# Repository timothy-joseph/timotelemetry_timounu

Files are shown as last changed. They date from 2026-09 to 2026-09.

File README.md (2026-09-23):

Data aquisition and transmission system
---

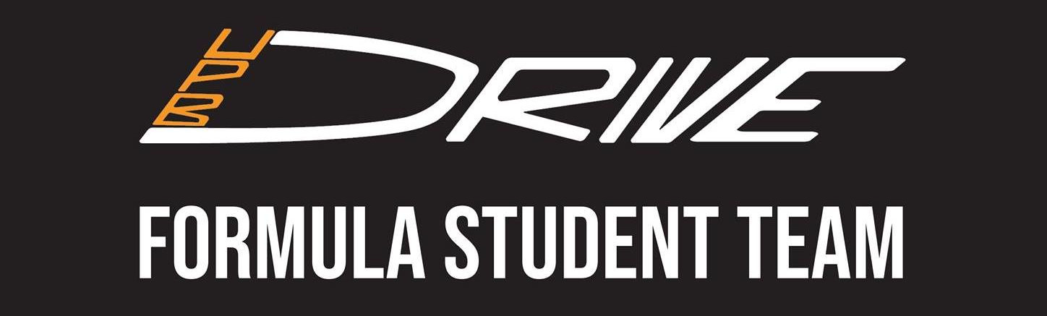
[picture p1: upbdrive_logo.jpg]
UPB Drive Logo UPB Drive logo


Formula Student Telemetry system I've developed in my first year of University
at UPB Drive

Kicad files are located in `Hardware/` and all software in `Software/` - th
firmware is located at `Software/dat\_software`, the GUI for the telemetry is
located at `Software/flask_mqtt_server`, and a helper program to load the
microsd logs in the interface is located at `Software/dat_microsd_log_to_json`

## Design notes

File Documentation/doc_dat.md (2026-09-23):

# Data acquisition and transmission

Purpose
---

The DAT system needs to collect data from the other modules and store it on a
microsd card, but also transmit it to the pits via 2 methods: MQTT and LoRa.\
The module also needs to have a RTC clock which will be set to either the time
retrieved via NTP or GPS at startup.\
The contents of the flash chip can be read by putting the module into a debug
mode and reading them through the onboard usb port.

Components used
---

### ESP32-S3-WROOM-1-N16R8

(TODO)

### Simcom7600e-h module from waveshare

This is the component that will handle data transmission via MQTT, but will
also get the current time and location of the vehicle.

The module has a UART interface using a 3 wire (TXD, RXD, GND) interface, but i
chose to also connect CTS and RTS for hardware control flow, DTR which puts the
module's uart interface in sleep mode, and RI which will cause a interrupt (high
to low) when receiving a phone call or sms. ([[1]] on page 7 to 11)\
Voltage in is between 5v and 26v, so I connected it to the 12v battery on the
car.\
The module also has a reset pin, which i connected to the esp32.
(Ground is connected to ground).\
All other pins can be left floating (as per the reference design or what i
deducted from the module schematic).

The module itself has a sim card slot and antenna inputs which will need to
be connected to a external antenna.

### LoRa-E5

This module provides LoRa wireless communication. It interfaces with the
microcontroller via a 3 wire (TXD, RXD, GND) UART interface, it also has a reset
pin, and a pin to enter boot upgrade mode. Besides these and power, all other
pins can be left floating as per the reference design. [[2]]

![Reference design](lora_reference_design.png "Reference design of the LoRa-E5
module")

### SN65HVD230DR

This is a CAN transciever with a speed for up to 1Mbps.

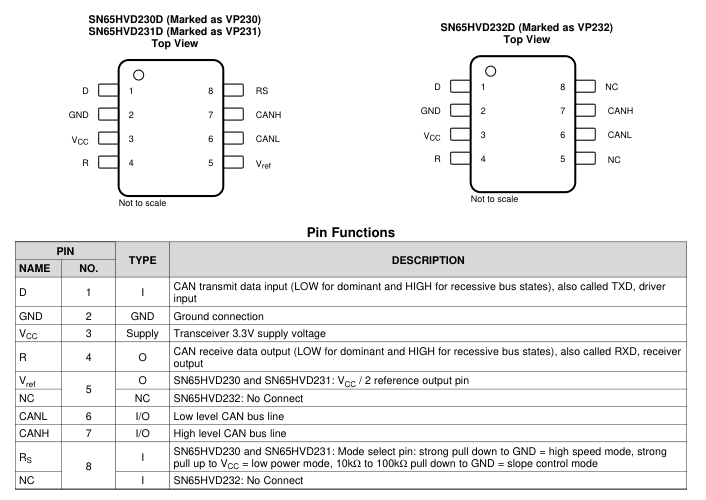
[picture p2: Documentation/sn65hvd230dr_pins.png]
SN65HVD230DR pins Pins of the SN65HVD230DR


### Miscrosd

The microsd is used to store logged data locally on multiple binary files.
The pins are connected according to the following reference design, but with
different IO pins on the esp32 side.

![Microsd reference](sch_micro_sd_slot.png "Reference design for the microsd
slot")

### MAX31331TETB+

The MAX31331TETB+ is a RTC chip with a backup supply pin, to which it will
switch automatically when the main supply drops below a programmed voltage.
The chip also features a trickle charger for the backup battery.
It is accessed through a I2C interface.

The VCC and GND pins are connected to the power supply.\
The SDA and SCL pins are connected to the I2C bus of the microcontroller.\
The X1 and X2 pins are connected to a external crystal.\
DIN is a input to the RTC and INTA is a interrupt generated by the RTC on:
Alarm2, timer, PFAIL, and DIN (configurable)\
INTB should be connected ground if unused.

![MAX31331TETB+ footprint](max31331tetb_footprint.png "The pins descriptions of
the MAX31331TETB+")
![MAX31331TETB+ pins](max31331tetb_pins.png "The pins descriptions of the
MAX31331TETB+")

### Power delivery

(TODO)

[1]: <https://www.microchip.ua/simcom/LTE/SIM7500_SIM7600/Application%20Notes/SIM7100_SIM7500_SIM7600%20Series_UART_Application%20Note_V3.00.pdf>
[2]: <https://files.seeedstudio.com/products/317990687/res/LoRa-E5%20module%20datasheet_V1.1.pdf> "LoRa-E5 datasheet"

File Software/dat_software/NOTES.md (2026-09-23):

### Dynamic Memory allocation

The rule "Dynamic allocation of memory is forbidden" has not been followed as
of writing this note, but the rule "Do not use dynamic memory allocation after
initialization" has been followed, except in one place.

Explanation:

- Besides the `can_receive_thread`, all other threads are created using the
  standard ESP's FreeRTOS `xTaskCreatePinnedToCore` which uses dynamic memory
  allocation (however, the stack's size does not change during operation)
  instead of `xTaskCreateStaticPinnedToCore`
- The esp idf's "release/v5.1" i2c driver uses dynamic memory allocation to
  create the command links

### MQTT packet

A mqtt packet is formed like this:

- 4 bytes representing the timestamp since logging began (us)
- 2 bytes representing the can id (made-up can id if it's not actually a can
  message)
- 1 byte representing data size
- a maximum of 8 data bytes

with 500-700 can messages per second => 60000 to 84000 bits per second of
packet data only. I might need to make the sim module's uart run at a higher
baud rate (higher than 400000)

The packet is in big-endian format.

### Driver configuration

When i set out to create the drivers for all of the peripherals of the DAT
system, i wanted them to be configurable in a similar way to how the drivers of
the esp-idf are configured, however due to time constraints, i have chosen to
make them configurable in another way: similar to how suckless software is
configured. All (configurable) components/drivers have a `component_config.h`
file which contains macros and/or variables to configure the driver's used
pins, stack sizes, thread priorities, queue sizes etc. These macros/variables
are explained briefly in comments above them and/or have suggestive names

### Sim driver

The sim driver has 3 components:

1. One to send commands
2. One to receive responses, interpret them and call callback functions (that
are defined within the same source file [this is another part that was rushed;
initially i wanted a system that binds responses to external callback
functions]);
3. One that enqueues the "AT+CGPSINFO" command every ??? (configurable) ms in
order to send it to the mqtt server

### RTC (MAX31331) chip's SDA and SCL pins

I accidentally swapped the SDA and SCL pins within the schematic when designing
it. That's why the pins are the swapped in software.

### Component initialization dependencies

rtc driver doesn't depend on anything
lora driver doesn't depend on anything
sim driver depends on rtc driver
microsd driver depends on rtc driver, sim driver
logging driver depends on sim driver, microsd driver, rtc driver, lora driver
can driver depends on logging

additionally the rtc driver has only one function that depends on the can
driver and so does the sim driver.

So the component initialization order is as follows:
1. can driver
2. rtc driver
3. sim driver
3.5 wait for the sim module to send the RDY flag (with a timeout)
4. lora driver
5. microsd driver and file
6. logging driver
7. can thread

`rtc_start_periodic_can_msg()` needs to be started from inside the receive
thread of the can driver

It might be a good idea to wait for the sim module to be ready before
initializing the microsd component. So the places that will wait for the sim
module are:

1. The `sim_commands_queue_thread` thread
2. `dat_setup()`

These places will have a timeout

\*: the module already `sim_commands_queue_thread()` already waits for the RDY
flag to be sent so it doesn't send any commands to the module before it's
initialized, but i think it's a good idea to wait in the `dat_setup()` function
also so the whole system is somewhat synced

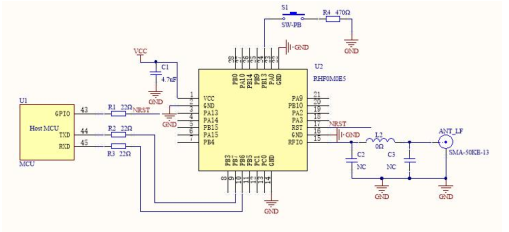
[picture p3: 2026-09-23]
Documentation/lora_reference_design.png

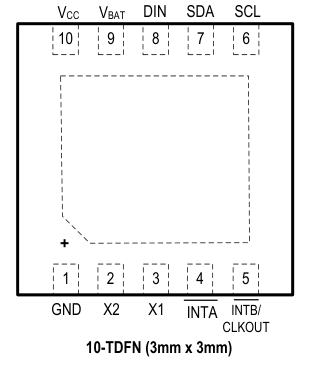
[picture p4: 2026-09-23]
Documentation/max31331tetb_footprint.png

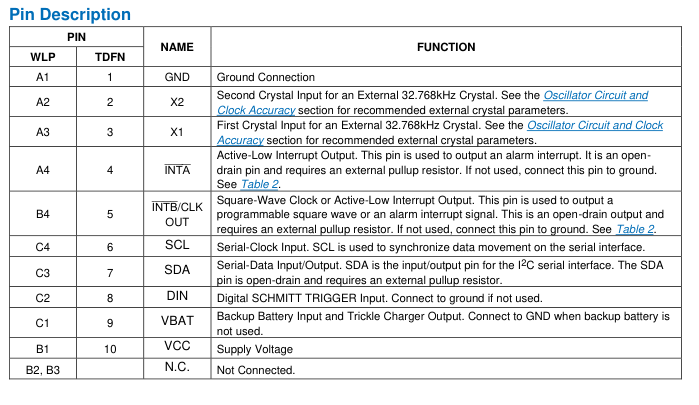
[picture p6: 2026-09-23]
Documentation/max31331tetb_pins.png

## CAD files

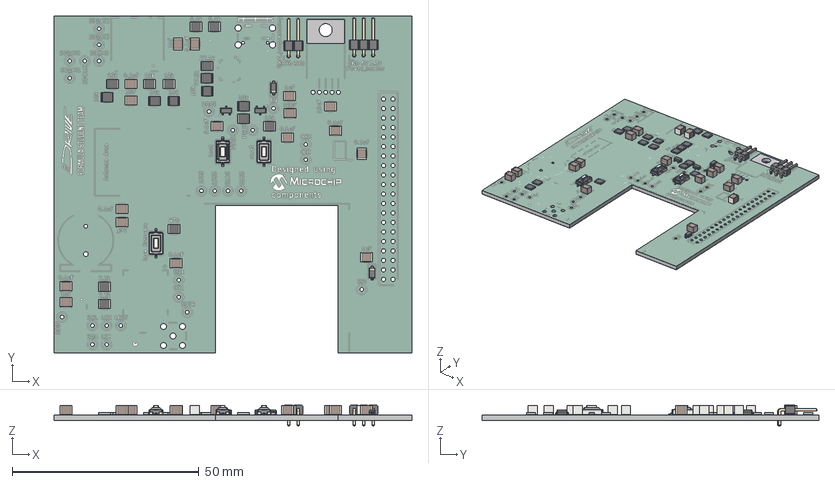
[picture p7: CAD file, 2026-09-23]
Hardware/PCB/dat.step
95.9 x 90.2 x 5.54 mm
C_1210_3225Metric x 17
R_1210_3225Metric x 17
SOT-23-3 x 2
D_SOD-123 x 2
PinHeader_1x03_P2.54mm_Horizontal
SW_Tactile_SPST_NO_Straight_CK_PTS636Sx25SMTRLFS x 3
PinHeader_1x02_P2.54mm_Horizontal
dat_silkscreen
dat_soldermask
dat_PCB

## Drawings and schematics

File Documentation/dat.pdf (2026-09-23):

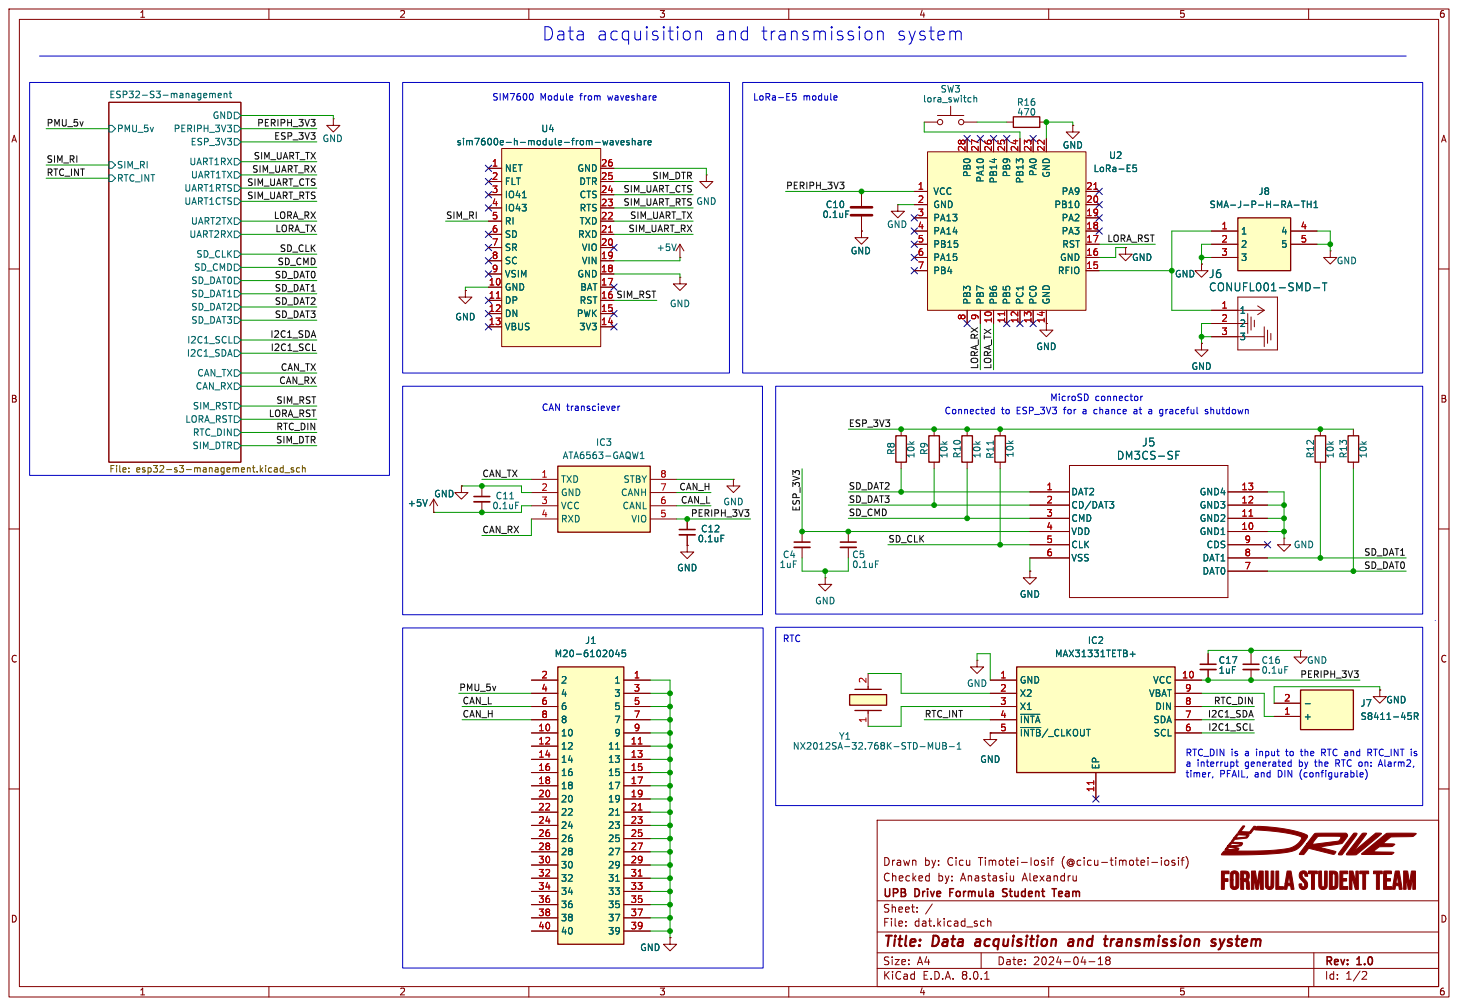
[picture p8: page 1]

1 2 Y1 NX2012SA-32.768K-STD-MUB-1 GND 1 VCC 10 EP 11 X2 2 X1 3 ~{INTA} 4 ~{INTB}/_CLKOUT 5 SCL 6 SDA 7 DIN 8 VBAT 9

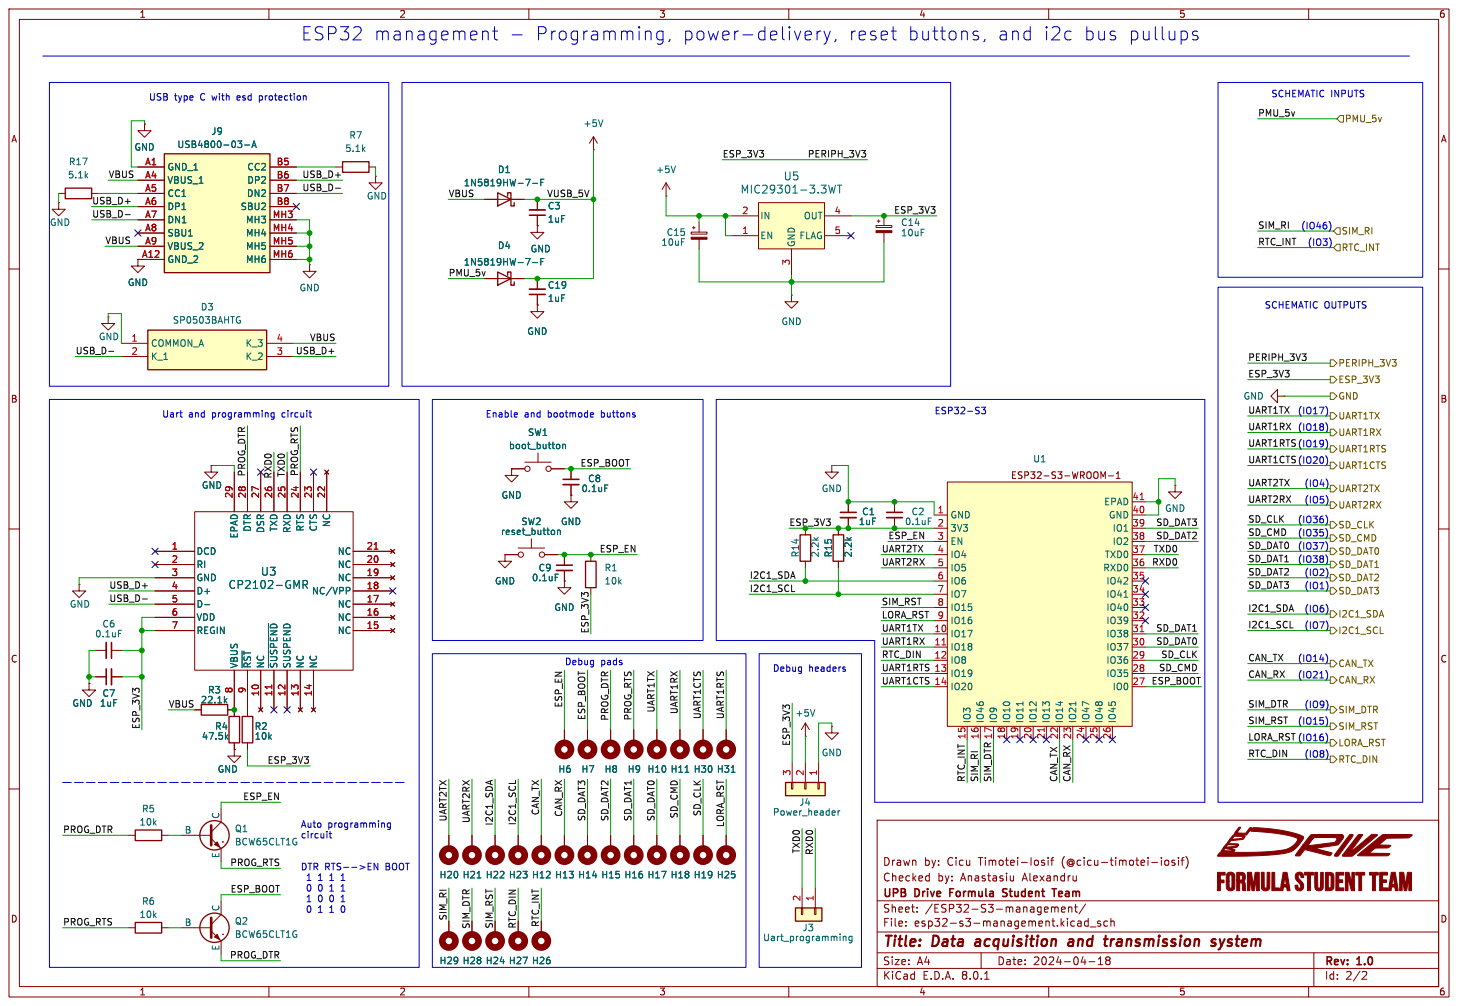
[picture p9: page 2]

8 ~{SUSPEND} 11 EPAD 29 ~{RST} 9 U3 CP2102-GMR

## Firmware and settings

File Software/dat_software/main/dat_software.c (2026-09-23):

/**
 * The components of the DAT system are
 * 1. can component:
 *      - listen for incoming messages on can and send them via 3 channels:
 *      + using mqtt to a central server: 4 bytes representing ms since the can
 *      component was started, 4 bytes representing the can id, 1 byte
 *      representing data size, then a maximum of 8 data bytes (big endian
 *      format)
 *      + lora to the pits: format TODO
 *      + local logging: same format as the mqtt packets
 * 2. sim component:
 *      - commands can be enqueued (by the other components; mainly the can
 *      component) for the sim component to execute (using a 2 thread model:
 *      uart_rx_thread, uart_execute_commands_thread)
 *      - the uart_rx_thread has callbacks for connlost to reconnect to the
 *      mqtt server and for gpsinfo to extract the data and send it on the can
 *      network (using the can component; the can component will then receive
 *      this message and log it); another callback can be used to update the
 *      rtc to the current date on startup.
 * 3. rtc component:
 *      - this can be programmed using the correct date at the pits (if it is
 *      determined that the sim module isn't working correctly to extract the
 *      current date)
 *
 * Besides the can component, data is logged (using the same 3 methods) in
 * another place also: at the setup phase of the system. Here the current date
 * is logged using a pseudo can id in order to keep the packet consistent.
 *
 * The mqtt server translates the mqtt packets into json and then plots them on
 * a webpage. The json can be saved locally and loaded on the same webpage at a
 * later date.
 *
 * With the DAT system, there will also be a utility created for translating
 * the data logged unto the microsd card (mqtt packets) into json that can then
 * be loaded using the above mentioned website
 */
/* TODO (no order):
 * CAN component calls vs component which updates the rtc based on time
 * received from PMU
 * GPS for sim module
 */
#include <stdio.h>
#include <string.h>

#include <driver/gpio.h>
#include <driver/twai.h>
#include <driver/i2c.h>
#include <esp_vfs_fat.h>
#include <esp_err.h>
#include <esp_log.h>

#include <freertos/FreeRTOS.h>
#include <freertos/task.h>
#include <freertos/queue.h>
#include <freertos/semphr.h>

#include <rtc_max31331.h>
#include <sim7600x_h.h>
#include <microsd.h>
#include <logging.h>
#include <can.h>
#include <vehicle_status.h>

#define DAT_TAG "DAT (main component)"

static void dat_setup(void);
/**
 * Function used to initialize all of the peripherals and threads of the dat
 * system.
 */
static void
dat_setup(void)
{
	struct rtc_calendar_t time;
	int ret;

	/* can pins setup */
	if (can_setup()) {
		ESP_LOGE(DAT_TAG, "Failed to install can driver\n");
		return;
	}

	/* RTC */
	if (rtc_i2c_init())
		ESP_LOGW(DAT_TAG, "failed to initialize the rtc\n");

	/* sim */
	if (sim_init_uart())
		ESP_LOGW(DAT_TAG, "Could not start the uart for the sim\n");
	if (sim_wait_for_rdy())
		ESP_LOGW(DAT_TAG,
			 "The sim module did not send the RDY flag in time\n");
	if (sim_setup_module())
		ESP_LOGW(DAT_TAG, "Could not connect to mqtt\n");

	if (microsd_init_driver())
		ESP_LOGW(DAT_TAG, "Could not initialize microsd\n");

	if (microsd_init_filename())
		ESP_LOGW(DAT_TAG, "Could not initialize microsd filename\n");

	logging_init_component();

	if (can_create_receive_thread() == NULL)
		ESP_LOGE(DAT_TAG, "Could not start the can thread\n");

	if (vs_init())
		ESP_LOGW(DAT_TAG,
			 "Could not initialize the vehicle_status component\n");
}

void
app_main(void)
{
	dat_setup();
}

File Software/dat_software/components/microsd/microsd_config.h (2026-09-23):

/*
 * File containing the configuration for the microsd driver
 * - log tag
 * - pins for the data and clock lines
 * - default filename in the case that a file can't be opened with the name as
 * the current timestamp
 */
#ifndef MICROSD_CONFIG_H
#define MICROSD_CONFIG_H

/*
 * The tag that will be used for the esp_log functions
 */
#define MICROSD_TAG "microsd"

#define MICROSD_BASE_PATH "/sd"
/*
 * if reading from the rtc fails, then this will be then this will be the name
 * of the file that the DAT system will write to
 */
#define MICROSD_DEFAULT_FILENAME "log.txt"
#define MICROSD_FOPEN_MODE "ab"

/*
 * pins
 */
#define MICROSD_CLK GPIO_NUM_36
#define MICROSD_CMD GPIO_NUM_35
#define MICROSD_DAT0 GPIO_NUM_37
#define MICROSD_DAT1 GPIO_NUM_38
#define MICROSD_DAT2 GPIO_NUM_2
#define MICROSD_DAT3 GPIO_NUM_1

/*
 * other configs
 */
#define MICROSD_FORMAT_IF_MOUNT_FAILED 0
#define MICROSD_MAX_FILES 5

#endif

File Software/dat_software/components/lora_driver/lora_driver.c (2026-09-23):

#include <stdio.h>
#include <string.h>

#include <esp_log.h>
#include <esp_check.h>
#include <driver/gpio.h>
#include <driver/uart.h>

#include <freertos/FreeRTOS.h>
#include <freertos/task.h>
#include <freertos/queue.h>
#include <freertos/semphr.h>

#include <lora_driver.h>

#define LORA_LOG_TAG "lora_driver"

/* defined here to changing between normal mode and TEST mode hex format is
 * easy. (AT_NORMAL_MODE or AT_TEST_MODE should be defined in lora_driver.h")
 */
#ifdef AT_NORMAL_MODE
#define AT_HEXMSG_FMT "AT+MSGHEX=\"%s\"\r\n"
#define AT_HEXMSG_EXPECTED "+MSGHEX: Done"
#define AT_RXMSG_DETECT "RX: \""
#endif

#ifdef AT_TEST_MODE
#define AT_HEXMSG_FMT "AT+TEST=TXLRPKT, \"%s\"\r\n"
#define AT_HEXMSG_EXPECTED "+TEST: TX DONE"
#define AT_RXMSG_DETECT "+TEST: RX"
#endif

static int lora_send_await_response(struct lora_dev_t *handle,
				    char *expected_response,
				    char *command, ...);
static int lora_config_via_at_commands(struct lora_dev_t *handle);
static int lora_nrmlcfg_via_at_commands(struct lora_dev_t *handle);
static int lora_testcfg_via_at_commands(struct lora_dev_t *handle);
static int lora_config_via_at_cmds_recv(struct lora_dev_t *handle);
static void lora_received_response_cb(struct lora_dev_t *handle, char *resp);
static void lora_message_cb(struct lora_dev_t *handle, char *resp);
static inline char __int_to_hex_digit(uint8_t digit);
static inline uint8_t __hex_to_int_digit(char digit);
static inline uint8_t __is_hex_digit(char digit);
static void lora_uart_rx_thread(void *args);
static void lora_sender_thread(void *args);

int
lora_init_uart(struct lora_dev_t *handle, uart_port_t uart_num,
	       gpio_num_t tx_pin, gpio_num_t rx_pin, uint8_t rx_thread_prio,
	       TickType_t universal_timeout)
{
	int ret;
	uart_config_t uart_cfg = {
		.baud_rate = 9600,
		.data_bits = UART_DATA_8_BITS,
		.parity = UART_PARITY_DISABLE,
		.stop_bits = UART_STOP_BITS_1,
		.flow_ctrl = UART_HW_FLOWCTRL_DISABLE,
	};

	ESP_RETURN_ON_FALSE(handle, ESP_FAIL, LORA_LOG_TAG,
			    "handle is NULL inside of lora_init_uart\r\n");

	/* initialize the structure (should already be initialized) */
	handle->uart_num = uart_num;
	handle->universal_timeout = universal_timeout;
	handle->received_messages = NULL;

	/* create the response mutex (used by the uart event thread to safely
	 * change the latest response)
	 */
	handle->resp_mutex = xSemaphoreCreateMutex();
	if (!handle->resp_mutex)
		return ESP_FAIL;

	/* initialize the uart driver */
	ESP_RETURN_ON_ERROR(uart_param_config(uart_num, &uart_cfg),
			    LORA_LOG_TAG, "uart_config fail\r\n");
	ESP_RETURN_ON_ERROR(uart_set_pin(uart_num, tx_pin, rx_pin,
					 UART_PIN_NO_CHANGE,
					 UART_PIN_NO_CHANGE),
			    LORA_LOG_TAG, "uart_set_pin fail\r\n");
	ESP_RETURN_ON_ERROR(uart_driver_install(uart_num, 2048, 2048, 10,
					    &handle->uart_event_queue, 0),
			    LORA_LOG_TAG, "uart_driver_install fail\r\n");

	/* create uart event thread */
	ret = xTaskCreatePinnedToCore(lora_uart_rx_thread,
				      "lora_uart_rx_thread", 4096, NULL,
				      rx_thread_prio, NULL, tskNO_AFFINITY);
	if (ret != pdPASS) {
		ESP_LOGE(
		  LORA_LOG_TAG,
		  "Failed to create the thread for receiving uart events\r\n"
		  	);
		vSemaphoreDelete(handle->resp_mutex);
		return ESP_FAIL;
	}

	return lora_config_via_at_commands(handle);
}

int
lora_init_as_sender(struct lora_dev_t *handle, size_t queue_len,
		    int thread_priority)
{
	int ret;

	ESP_RETURN_ON_FALSE(handle, ESP_FAIL, LORA_LOG_TAG,
			    "handle is NULL inside of lora_init_as_sender\r\n");

	/* check if commands can be sent, if they can be sent, then configure
	 * the module as a sender
	 */
	handle->payload_queue = xQueueCreate(queue_len,
					     sizeof(struct lora_payload_t));
	ESP_RETURN_ON_FALSE(handle->payload_queue, ESP_FAIL, LORA_LOG_TAG,
			    "Failed to create the queue for the payloads\r\n");

	ret = xTaskCreatePinnedToCore(lora_sender_thread, "lora_sender_thread",
				      4096, handle, thread_priority, NULL,
				      tskNO_AFFINITY);
	if (ret != pdPASS) {
		ESP_LOGW(LORA_LOG_TAG,
			 "Failed to create the thread for sending queued payloads\r\n");
		vQueueDelete(handle->payload_queue);
		return ESP_FAIL;
	}

	return ESP_OK;
}

int
lora_init_as_receiver(struct lora_dev_t *handle, size_t msg_queue_len)
{
	ESP_RETURN_ON_FALSE(handle, ESP_FAIL, LORA_LOG_TAG,
			  "handle is NULL inside of lora_init_as_receiver\r\n");

	handle->received_messages = xQueueCreate(msg_queue_len,
						 sizeof(struct lora_message_t));
	ESP_RETURN_ON_FALSE(handle->received_messages, ESP_FAIL, LORA_LOG_TAG,
			    "Failed to create the queue for the messages\r\n");

	return lora_config_via_at_cmds_recv(handle);
}

int
lora_enqueue_command(struct lora_dev_t *handle, char *expected_response,
		     char *command, ...)
{
	struct lora_payload_t to_enq;
	va_list args;

	ESP_RETURN_ON_FALSE(handle, ESP_FAIL, LORA_LOG_TAG,
			    "handle is NULL inside of lora_enqueue_command\r\n"
			   );
	ESP_RETURN_ON_FALSE(command, ESP_FAIL, LORA_LOG_TAG,
			    "command is NULL inside of lora_enqueue_command\r\n"
			   );

	va_start(args, command);
	vsnprintf(to_enq.command, sizeof(to_enq.command), command, args);
	va_end(args);

	if (expected_response)
		strncpy(to_enq.expected_response, expected_response,
			sizeof(to_enq.expected_response));
	else
		to_enq.expected_response[0] = '\0';
	to_enq.expected_response[sizeof(to_enq.expected_response) - 1] = '\0';

	if (xQueueSend(handle->payload_queue, &to_enq,
		       handle->universal_timeout) != pdTRUE) {
		ESP_LOGW(LORA_LOG_TAG, "Couldn't add item to queue\r\n");
		return ESP_FAIL;
	}

	return ESP_OK;
}

int
lora_enqueue_hexmsg(struct lora_dev_t *handle, uint8_t *message,
		    size_t message_size)
{
	char hex_msg[LORA_COMMAND_LENGTH];
	size_t hex_msg_len, i;

	ESP_RETURN_ON_FALSE(handle, ESP_FAIL, LORA_LOG_TAG,
			    "handle is NULL inside of lora_enqueue_hexmsg\r\n"
			   );
	ESP_RETURN_ON_FALSE(message, ESP_FAIL, LORA_LOG_TAG,
			    "message is NULL inside of lora_enqueue_hexmsg\r\n"
			   );

	/* translate each byte of message into two bytes representing the hex
	 * value of that byte and put it at the end of hex_msg. hex_msg is
	 * null terminated
	 */
	memset(hex_msg, 0, sizeof(hex_msg));
	hex_msg_len = 0;
	for (i = 0; i < message_size && hex_msg_len < sizeof(hex_msg); i++) {
		hex_msg[hex_msg_len] = __int_to_hex_digit(message[i] >> 4);
		if (hex_msg_len + 1 >= sizeof(hex_msg))
			break;
		hex_msg[hex_msg_len + 1] = __int_to_hex_digit(message[i] & 0xf);
		hex_msg_len += 2;
	}
	hex_msg[sizeof(hex_msg) - 1] = '\0';

	return lora_enqueue_command(handle, AT_HEXMSG_EXPECTED,
				    AT_HEXMSG_FMT, hex_msg);
}
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

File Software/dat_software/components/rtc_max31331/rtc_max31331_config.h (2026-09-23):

/*
 * File contatining the configuration for the rtc driver:
 * - pins
 * - i2c frequency
 * - i2c internal pullups
 * - registers
 * - update interval for sending the current timestamp on the can network
 */
#ifndef RTC_MAX31331_CONFIG_H
#define RTC_MAX31331_CONFIG_H

/*
 * The tag that will be used for the esp_log functions
 */
#define MICROSD_TAG "microsd"
#define RTC_LOG_TAG "max31331"

/*
 * The address of the rtc chip
 */
#define RTC_ADDR 0x68

/*
 * RTC registers
 */
#define RTC_PWR_MGMT 0x1A
#define RTC_TRICKLE_REG 0x1B
#define RTC_SECONDS_1_128 0x07

/*
 * i2c config
 */
#define RTC_I2C_PORT I2C_NUM_0
#define RTC_I2C_SDA GPIO_NUM_7
#define RTC_I2C_SCL GPIO_NUM_6
#define RTC_I2C_PULLUP GPIO_PULLUP_DISABLE
#define RTC_CLK_SPEED_HZ 400000

/*
 * universal timeout: for functions that require a tick timeout, this will be
 * be the value passed to it. The value is in freertos ticks
 */
#define RTC_UNIVERSAL_TIMEOUT 100

/*
 * the ms between sending updates to the dashboard's clock
 */
#define RTC_DASH_UPDATE_INTERVAL_MS 500
#define RTC_CAN_ID 0x10

#endif
